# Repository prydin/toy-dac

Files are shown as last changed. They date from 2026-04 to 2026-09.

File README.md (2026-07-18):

# toy-dac

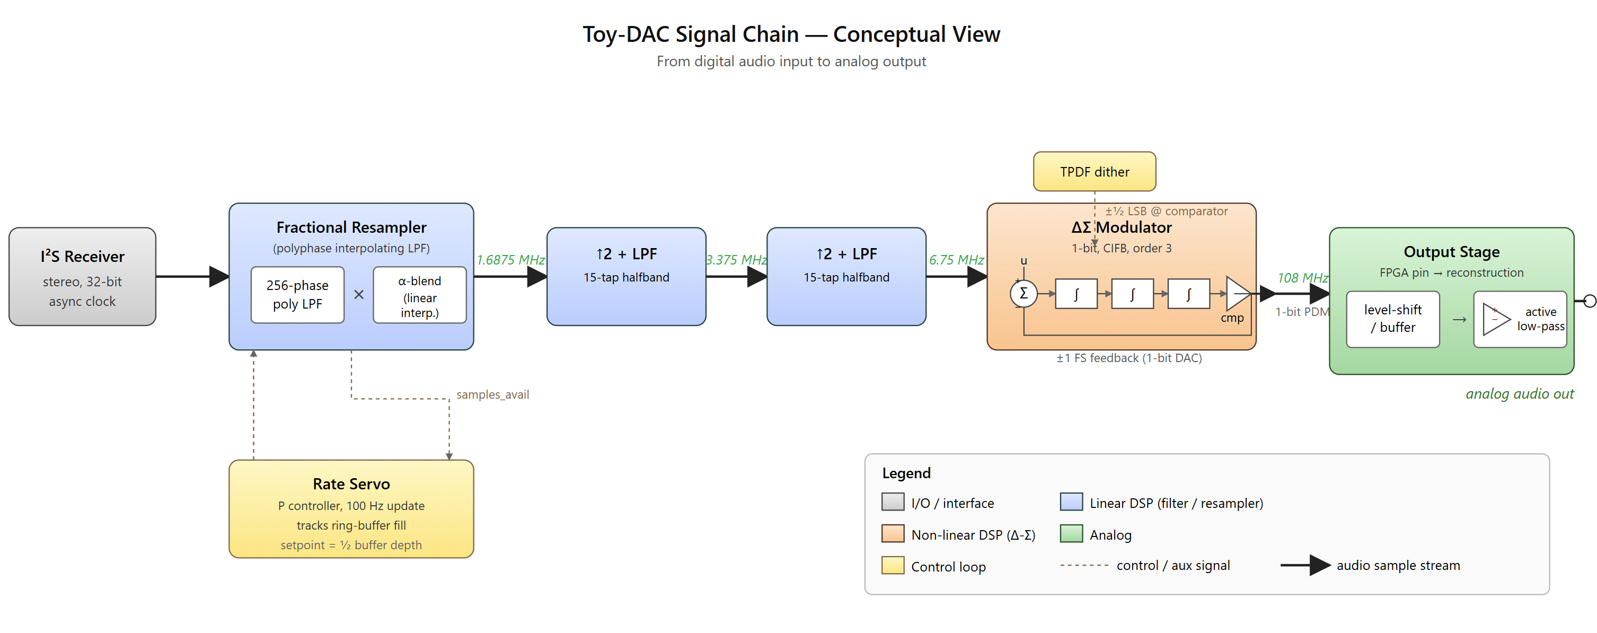
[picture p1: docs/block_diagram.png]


A 1-bit ΔΣ stereo audio DAC implemented on a Xilinx 7-series FPGA
(Digilent Cmod S7), driven from an I²S input.

The signal chain is entirely homemade RTL:

- **I²S receiver** with double-flopped synchronizers and AXI-Stream output
- **Automatic input rate detection** (32 / 44.1 / 48 kHz)
- **Fractional-phase polyphase ASRC** — 256 phases × 64 taps × 18-bit
  coefficients with 16-bit alpha lerp, single time-shared MAC, PI servo
  on the input ring-buffer fill — resampling onto a fixed
  Fs<sub>out</sub> = MCLK / 64 = 1.6875 MHz output grid
- **2nd-order CIFB ΔΣ modulator** (per channel) with TPDF dither,
  driving a single-bit differential output pin pair on each channel
- A small reconstruction filter and analog output stage on the carrier PCB

Internal test sources (silent, DC, 1 kHz DDS sine) and a bypass mode
(raw I²S → modulator) are included for bring-up and characterisation.

Achieved performance with the current build is roughly 70 dB SNR and
−74 dB THD at −7 dBFS, 1 kHz; harmonic distortion is dominated by the
analog stage on the prototype board.

## Status

**Experimental.** This is a personal learning / hobby project. The
design works end-to-end on the target hardware, but it has had limited
testing, no formal verification, and the analog board is a hand-routed
prototype. Module ports, parameter names, and pinouts may change without
notice. Use it for inspiration or as a starting point, not as a drop-in
IP.

## Repository layout

```
fpga/toy-dac/   Vivado project (RTL under src/rtl, constraints under
                toy-dac.srcs/constrs_1, simulation under toy-dac.srcs/sim_1)
kicad/dac/      KiCad schematic + PCB for the analog carrier board
scripts/        Coefficient generation, simulation helpers, sanity checks
docs/           Block diagrams (top-level + ASRC internals)
```

## Building

Open `fpga/toy-dac/toy-dac.xpr` in Vivado 2024.2, run synthesis +
implementation + bitstream generation, and program the Cmod S7. The
target part and pin assignments live in
`fpga/toy-dac/toy-dac.srcs/constrs_1/new/root.xdc`.

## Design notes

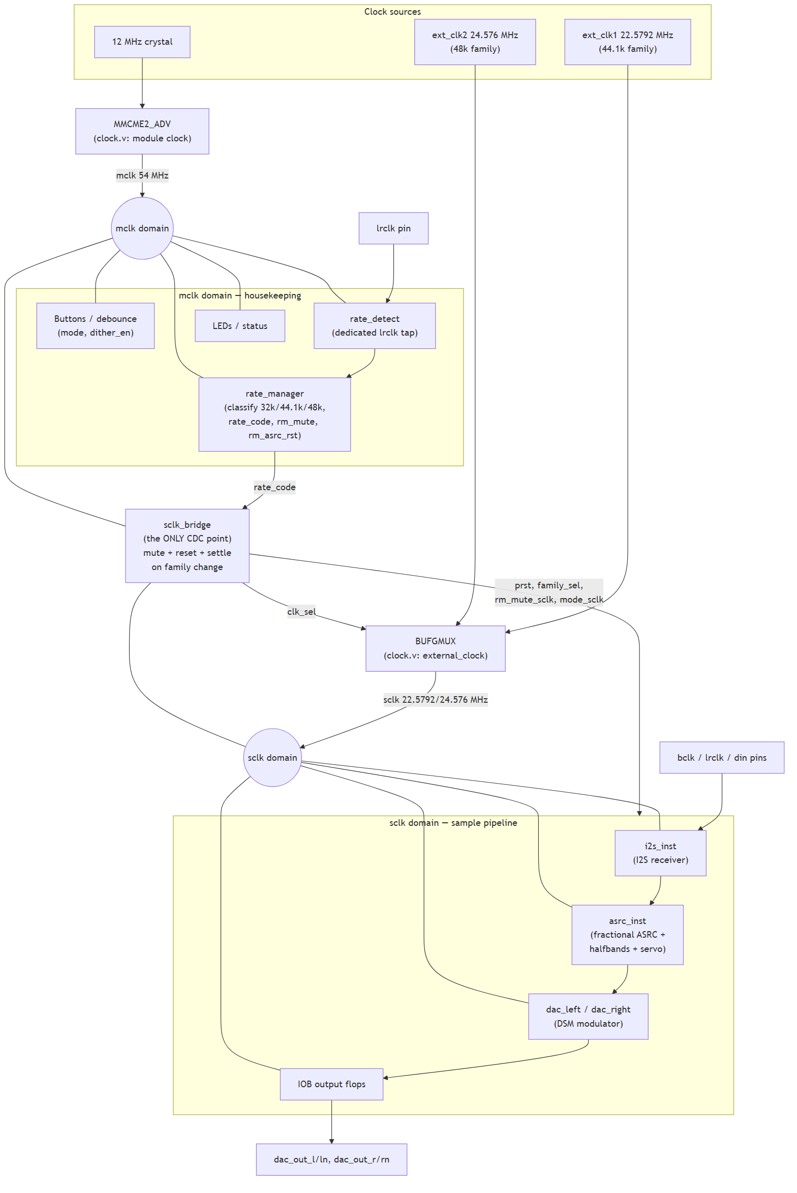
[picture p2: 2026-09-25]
docs/clock_domains.png

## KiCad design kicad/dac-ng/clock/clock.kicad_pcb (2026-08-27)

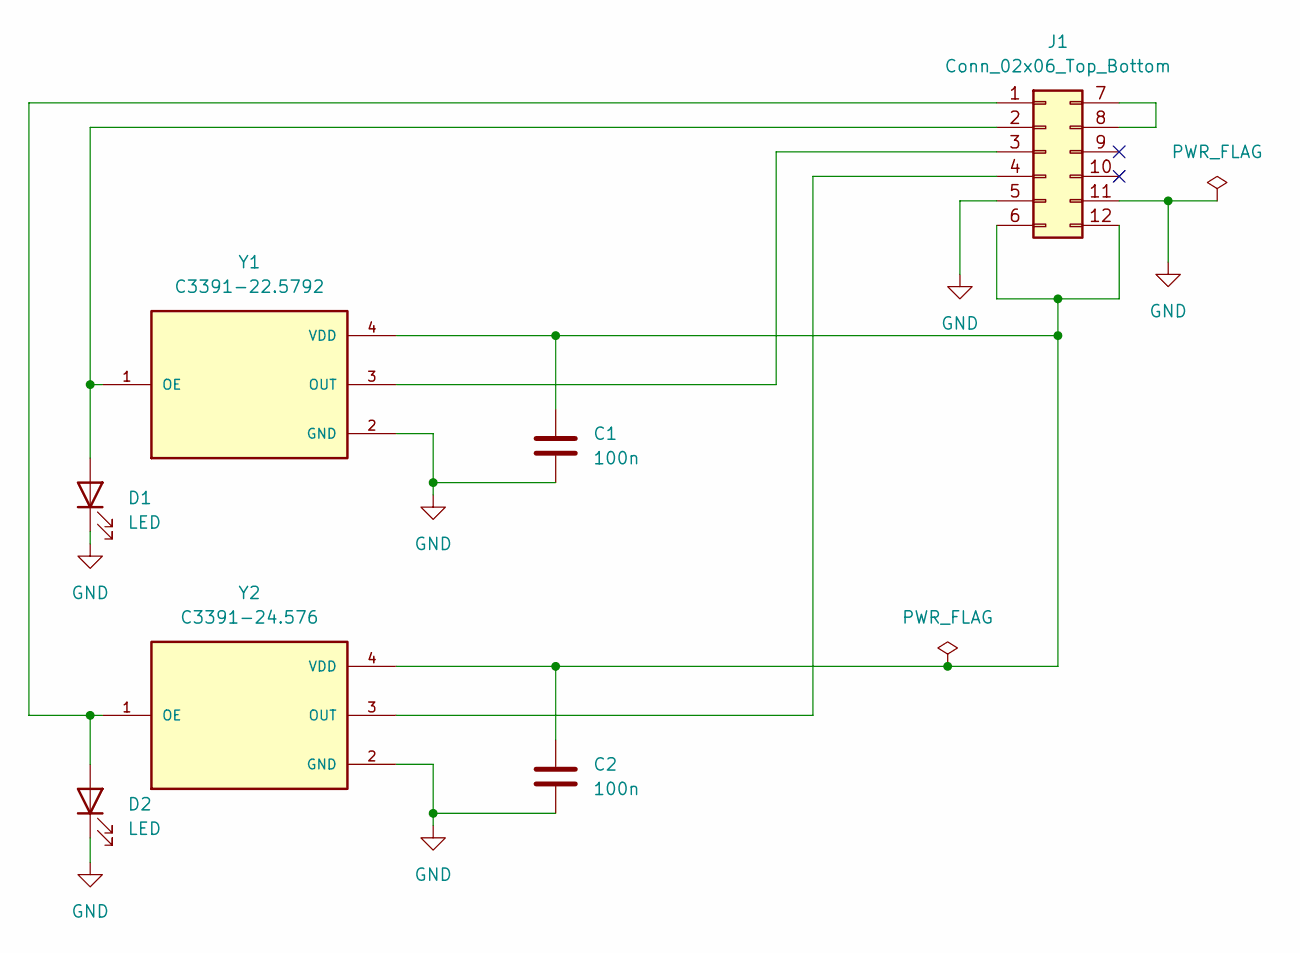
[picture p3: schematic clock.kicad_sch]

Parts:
C1, C2: 100n; C_0603_1608Metric_Pad1.08x0.95mm_HandSolder
D1, D2: LED; LED_0603_1608Metric
J1: Conn_02x06_Top_Bottom; PinHeader_2x06_P2.54mm_Vertical
Y1: C3391-22.5792; Oscillator_SMD_Diodes_FN-4Pin_7.0x5.0mm; PARTREV NA
Y2: C3391-24.576; Oscillator_SMD_Diodes_FN-4Pin_7.0x5.0mm; PARTREV NA

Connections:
GND: C1.2, C2.2, D1.1 (K), D2.1 (K), J1.5, J1.11, Y1.2 (GND), Y2.2 (GND)
unnamed: D1.2 (A), J1.2, Y1.1 (OE)
unnamed: D2.2 (A), J1.1, Y2.1 (OE)
unnamed: J1.3, Y1.3 (OUT)
unnamed: J1.4, Y2.3 (OUT)
unnamed: J1.7, J1.8
unnamed: C1.1, C2.1, J1.6, J1.12, Y1.4 (VDD), Y2.4 (VDD)

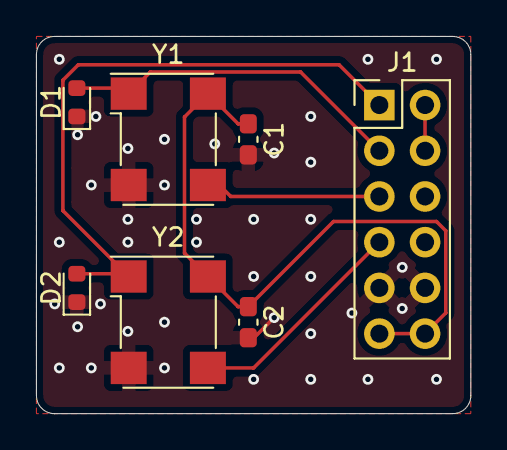
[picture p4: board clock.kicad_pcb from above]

Board: 2 copper layers, 24.1 x 21.0 mm, 7 parts (0 on the bottom side), 7 nets.

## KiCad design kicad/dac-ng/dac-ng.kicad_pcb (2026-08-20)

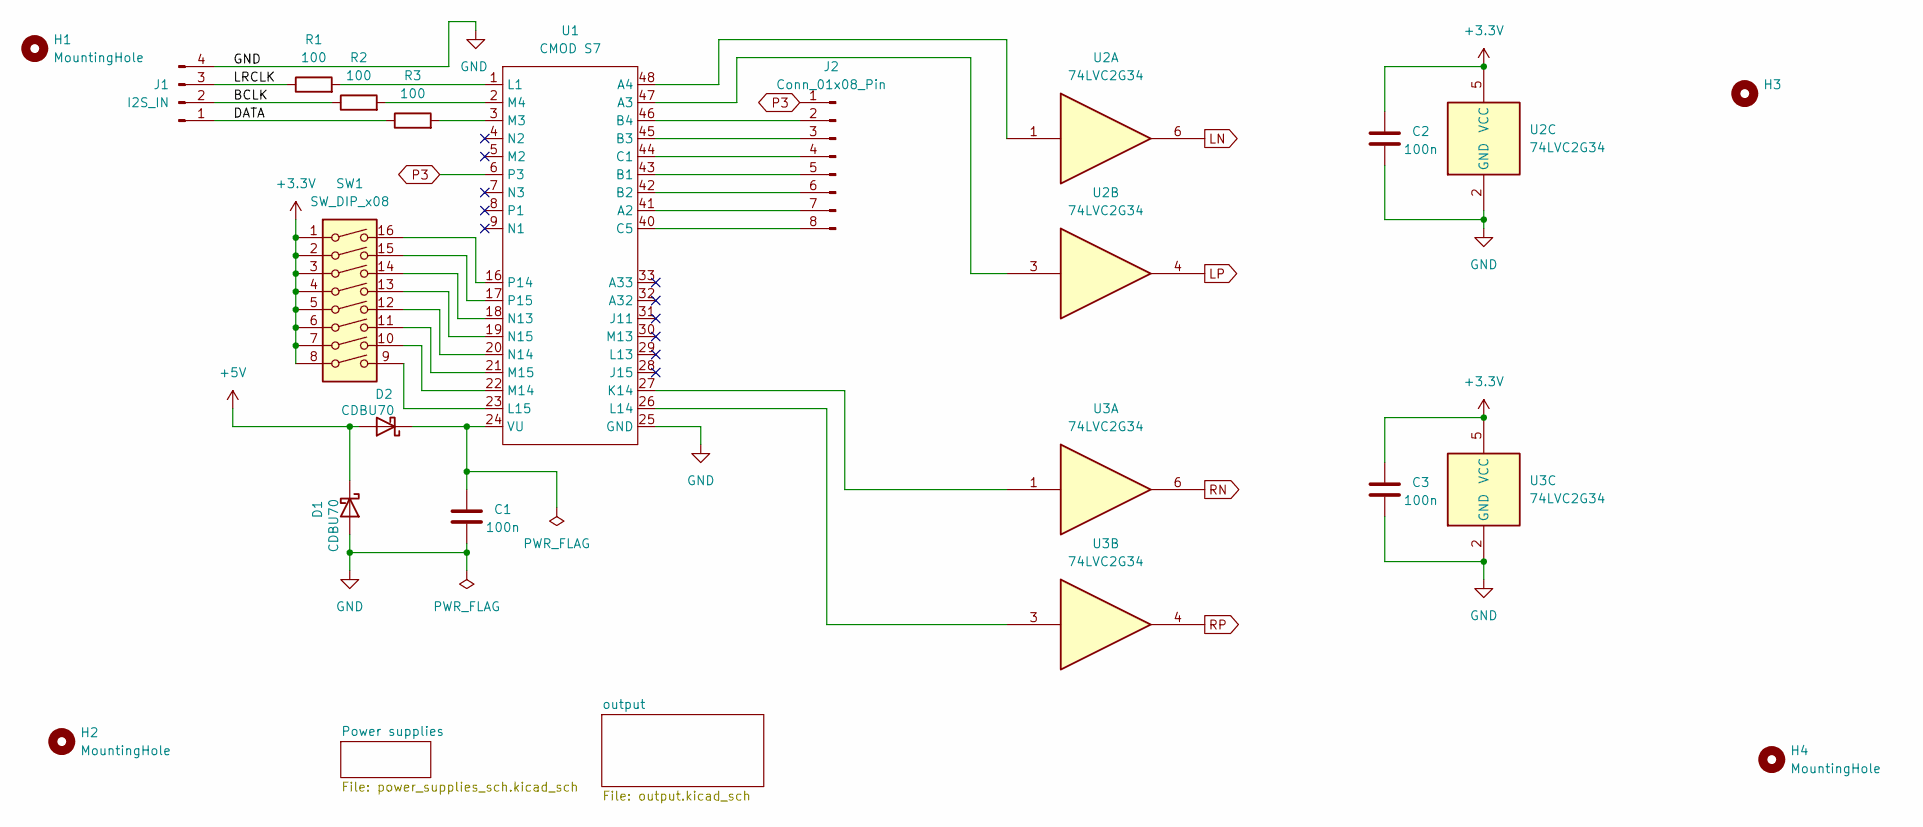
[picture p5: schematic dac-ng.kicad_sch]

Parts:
C1, C2, C3: 100n; C_0603_1608Metric_Pad1.08x0.95mm_HandSolder
D1, D2: CDBU70; D_0603_1608Metric
H1, H2, H3, H4: MountingHole; MountingHole_3.2mm_M3
J1: I2S_IN; JST_PH_B4B-PH-K_1x04_P2.00mm_Vertical
J2: Conn_01x08_Pin; PinHeader_1x08_P2.54mm_Vertical
R1, R2, R3: 100; R_0603_1608Metric_Pad0.98x0.95mm_HandSolder
SW1: SW_DIP_x08; SW_DIP_SPSTx08_Slide_6.7x21.88mm_W7.62mm_P2.54mm_LowProfile
U1: CMOD S7
U2, U3: 74LVC2G34; SOT-363_SC-70-6

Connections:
+3.3V: C2.2, C3.2, SW1.1, SW1.2, SW1.3, SW1.4, SW1.5, SW1.6, SW1.7, SW1.8, U2.5 (VCC), U3.5 (VCC); also elsewhere on the board
+5V: D1.1 (K), D2.2 (A); also elsewhere on the board
/BCLK: J1.2, R2.1
/DATA: J1.1, R3.1
/LRCLK: J1.3, R1.1
GND: C1.1, C2.1, C3.1, D1.2 (A), J1.4, U1.25 (GND), U2.2 (GND), U3.2 (GND); also elsewhere on the board
LN: U2.6; also elsewhere on the board
LP: U2.4; also elsewhere on the board
unnamed: C1.2, D2.1 (K), U1.24 (VU)
unnamed: J2.2, U1.46 (B4)
unnamed: J2.3, U1.45 (B3)
unnamed: J2.4, U1.44 (C1)
unnamed: J2.5, U1.43 (B1)
unnamed: J2.6, U1.42 (B2)
unnamed: J2.7, U1.41 (A2)
unnamed: J2.8, U1.40 (C5)
unnamed: U1.47 (A3), U2.3
unnamed: U1.48 (A4), U2.1
unnamed: U1.27 (K14), U3.1
unnamed: R1.2, U1.1 (L1)
unnamed: U1.26 (L14), U3.3
unnamed: SW1.9, U1.23 (L15)
unnamed: R3.2, U1.3 (M3)
unnamed: R2.2, U1.2 (M4)
unnamed: SW1.10, U1.22 (M14)
unnamed: SW1.11, U1.21 (M15)
unnamed: SW1.14, U1.18 (N13)
unnamed: SW1.12, U1.20 (N14)
unnamed: SW1.13, U1.19 (N15)
unnamed: SW1.16, U1.16 (P14)
unnamed: SW1.15, U1.17 (P15)
P3: J2.1, U1.6 (P3)
RN: U3.6; also elsewhere on the board
RP: U3.4; also elsewhere on the board

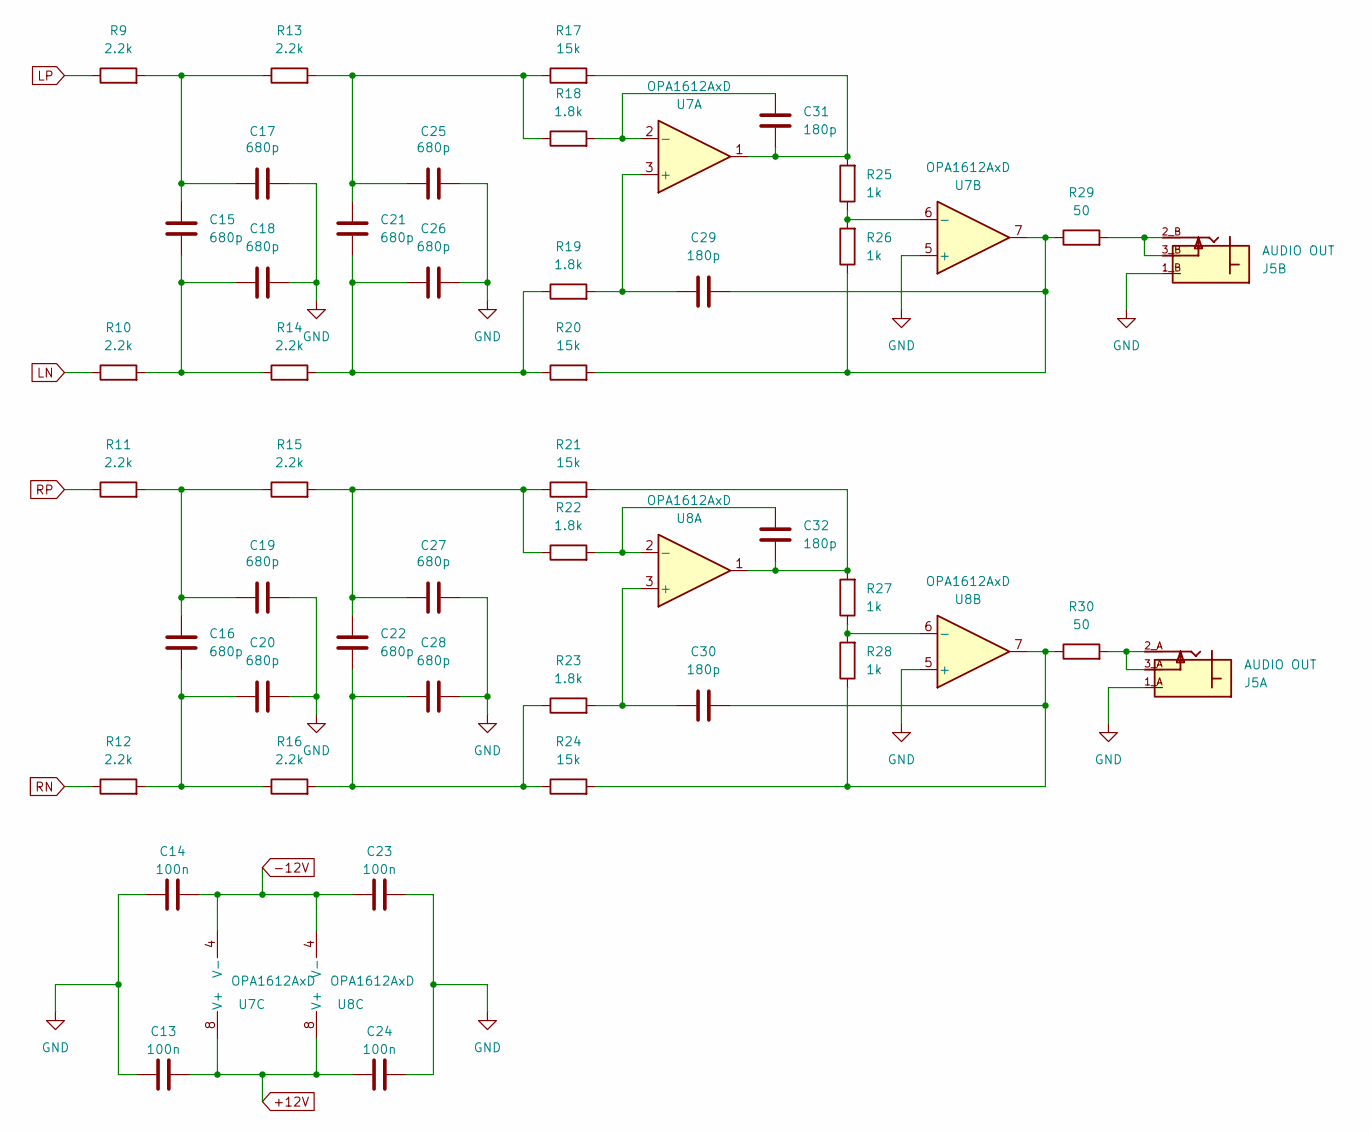
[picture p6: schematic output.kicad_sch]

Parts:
C13, C14, C23, C24: 100n; C_0603_1608Metric_Pad1.08x0.95mm_HandSolder
C15, C16, C17, C18, C19, C20, C21, C22, C25, C26, C27, C28: 680p; C_0603_1608Metric_Pad1.08x0.95mm_HandSolder
C29, C30, C31, C32: 180p; C_0603_1608Metric_Pad1.08x0.95mm_HandSolder
J5: AUDIO OUT; SWITCHCRAFT_PJRAN2X1U01AUX
R9, R10, R11, R12, R13, R14, R15, R16: 2.2k; R_0603_1608Metric_Pad0.98x0.95mm_HandSolder
R17, R20, R21, R24: 15k; R_0603_1608Metric_Pad0.98x0.95mm_HandSolder
R18, R19, R22, R23: 1.8k; R_0603_1608Metric_Pad0.98x0.95mm_HandSolder
R25, R26, R27, R28: 1k; R_0603_1608Metric_Pad0.98x0.95mm_HandSolder
R29, R30: 50; R_0603_1608Metric_Pad0.98x0.95mm_HandSolder
U7, U8: OPA1612AxD; SOIC-8_5.3x5.3mm_P1.27mm

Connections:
+12V: C13.2, C24.2, U7.8 (V+), U8.8 (V+); also elsewhere on the board
-12V: C14.2, C23.2, U7.4 (V-), U8.4 (V-); also elsewhere on the board
GND: C13.1, C14.1, C17.2, C18.2, C19.2, C20.2, C23.1, C24.1, C25.2, C26.2, C27.2, C28.2, J5.1_A, J5.1_B, U7.5 (+), U8.5 (+); also elsewhere on the board
LN: R10.1; also elsewhere on the board
LP: R9.1; also elsewhere on the board
unnamed: C15.1, C17.1, R9.2, R13.1
unnamed: C15.2, C18.1, R10.2, R14.1
unnamed: C16.1, C19.1, R11.2, R15.1
unnamed: C16.2, C20.1, R12.2, R16.1
unnamed: C21.1, C25.1, R13.2, R17.1, R18.1
unnamed: C21.2, C26.1, R14.2, R19.1, R20.1
unnamed: C22.1, C27.1, R15.2, R21.1, R22.1
unnamed: C22.2, C28.1, R16.2, R23.1, R24.1
unnamed: C29.2, R20.2, R26.1, R29.1, U7.7
unnamed: C30.2, R24.2, R28.1, R30.1, U8.7
unnamed: C31.2, R17.2, R25.2, U7.1
unnamed: C32.2, R21.2, R27.2, U8.1
unnamed: J5.2_A, J5.3_A, R30.2
unnamed: J5.2_B, J5.3_B, R29.2
unnamed: C29.1, R19.2, U7.3 (+)
unnamed: C31.1, R18.2, U7.2 (-)
unnamed: R25.1, R26.2, U7.6 (-)
unnamed: C30.1, R23.2, U8.3 (+)
unnamed: C32.1, R22.2, U8.2 (-)
unnamed: R27.1, R28.2, U8.6 (-)
RN: R12.1; also elsewhere on the board
RP: R11.1; also elsewhere on the board

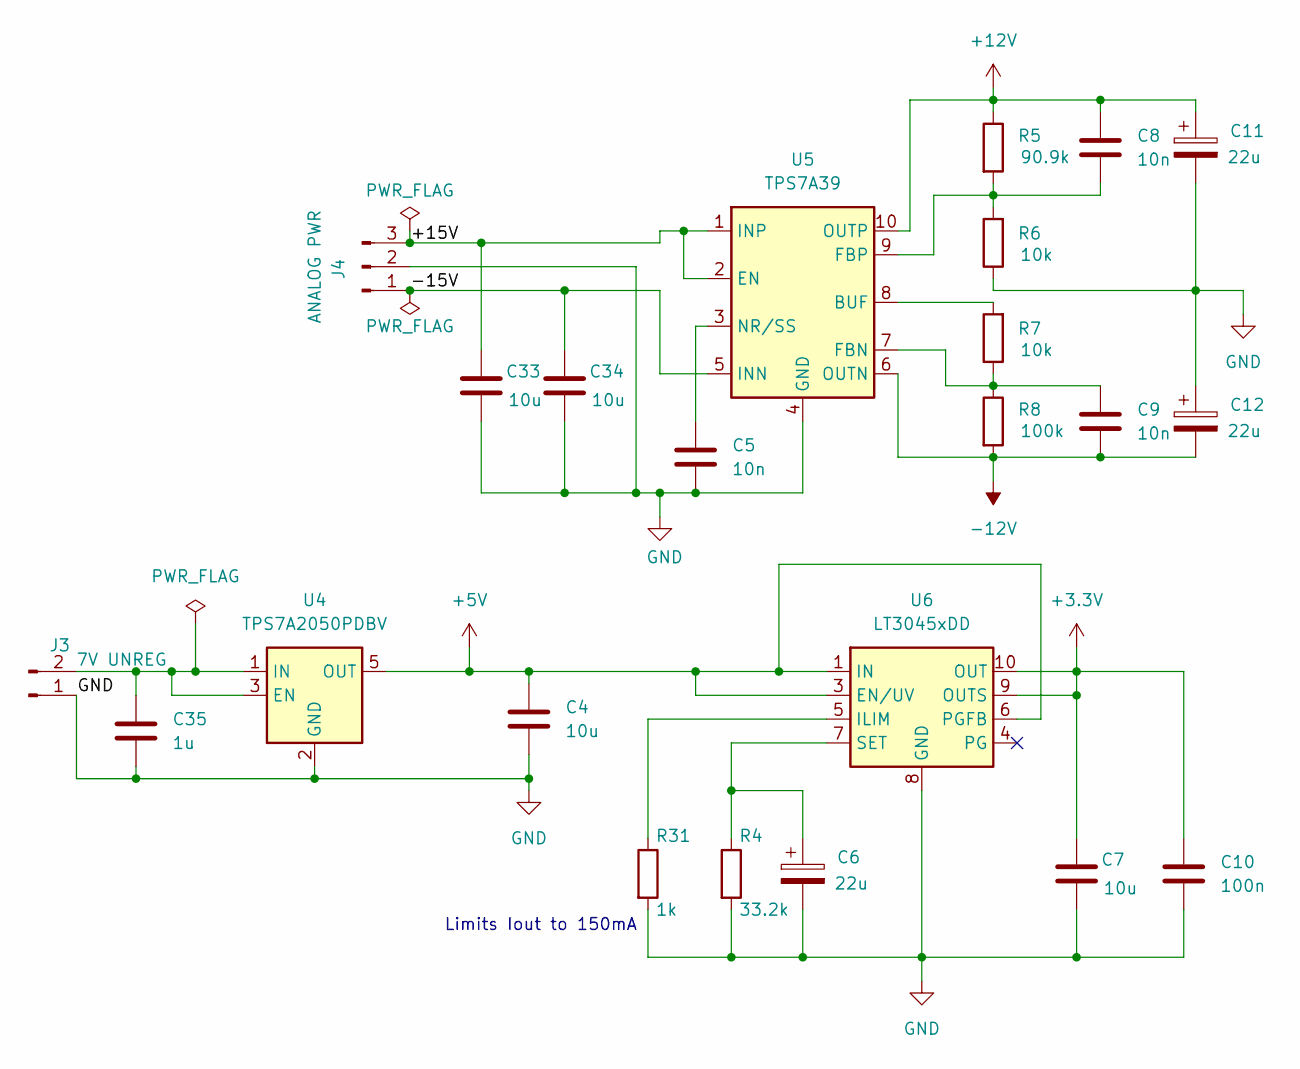
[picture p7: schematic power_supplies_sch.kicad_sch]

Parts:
C4, C7, C33, C34: 10u; C_0805_2012Metric
C5, C8, C9: 10n; C_0603_1608Metric_Pad1.08x0.95mm_HandSolder
C6, C11, C12: 22u; CP_EIA-3216-10_Kemet-I_HandSolder
C10: 100n; C_0603_1608Metric_Pad1.08x0.95mm_HandSolder
C35: 1u; C_0603_1608Metric
J3: 7V UNREG; JST_PH_B2B-PH-K_1x02_P2.00mm_Vertical
J4: ANALOG PWR; JST_PH_B3B-PH-K_1x03_P2.00mm_Vertical
R4: 33.2k; R_0603_1608Metric_Pad0.98x0.95mm_HandSolder
R5: 90.9k; R_0603_1608Metric_Pad0.98x0.95mm_HandSolder
R6, R7: 10k; R_0603_1608Metric_Pad0.98x0.95mm_HandSolder
R8: 100k; R_0603_1608Metric_Pad0.98x0.95mm_HandSolder
R31: 1k; R_0603_1608Metric_Pad0.98x0.95mm_HandSolder
U4: TPS7A2050PDBV; SOT-23-5
U5: TPS7A39; Texas_S-PVSON-N10_ThermalVias
U6: LT3045xDD; DFN-10-1EP_3x3mm_P0.5mm_EP1.65x2.38mm

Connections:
+3.3V: C7.1, C10.1, U6.9 (OUTS), U6.10 (OUT); also elsewhere on the board
+5V: C4.1, U4.5 (OUT), U6.1 (IN), U6.2 (IN), U6.3 (EN/UV), U6.6 (PGFB); also elsewhere on the board
+12V: C8.1, C11.1, R5.1, U5.10 (OUTP); also elsewhere on the board
-12V: C9.2, C12.2, R8.2, U5.6 (OUTN); also elsewhere on the board
/Power supplies/+15V: C33.1, J4.3, U5.1 (INP), U5.2 (EN)
/Power supplies/-15V: C34.1, J4.1, U5.5 (INN)
GND: C4.2, C5.2, C6.2, C7.2, C10.2, C11.2, C12.1, C33.2, C34.2, C35.2, J3.1, J4.2, R4.2, R6.1, R31.2, U4.2 (GND), U5.4 (GND), U5.11 (GND), U6.8 (GND), U6.11 (GND); also elsewhere on the board
unnamed: C35.1, J3.2, U4.1 (IN), U4.3 (EN)
unnamed: R7.2, U5.8 (BUF)
unnamed: C9.1, R7.1, R8.1, U5.7 (FBN)
unnamed: C8.2, R5.2, R6.2, U5.9 (FBP)
unnamed: C5.1, U5.3 (NR/SS)
unnamed: R31.1, U6.5 (ILIM)
unnamed: C6.1, R4.1, U6.7 (SET)

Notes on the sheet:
Limits Iout to 150mA

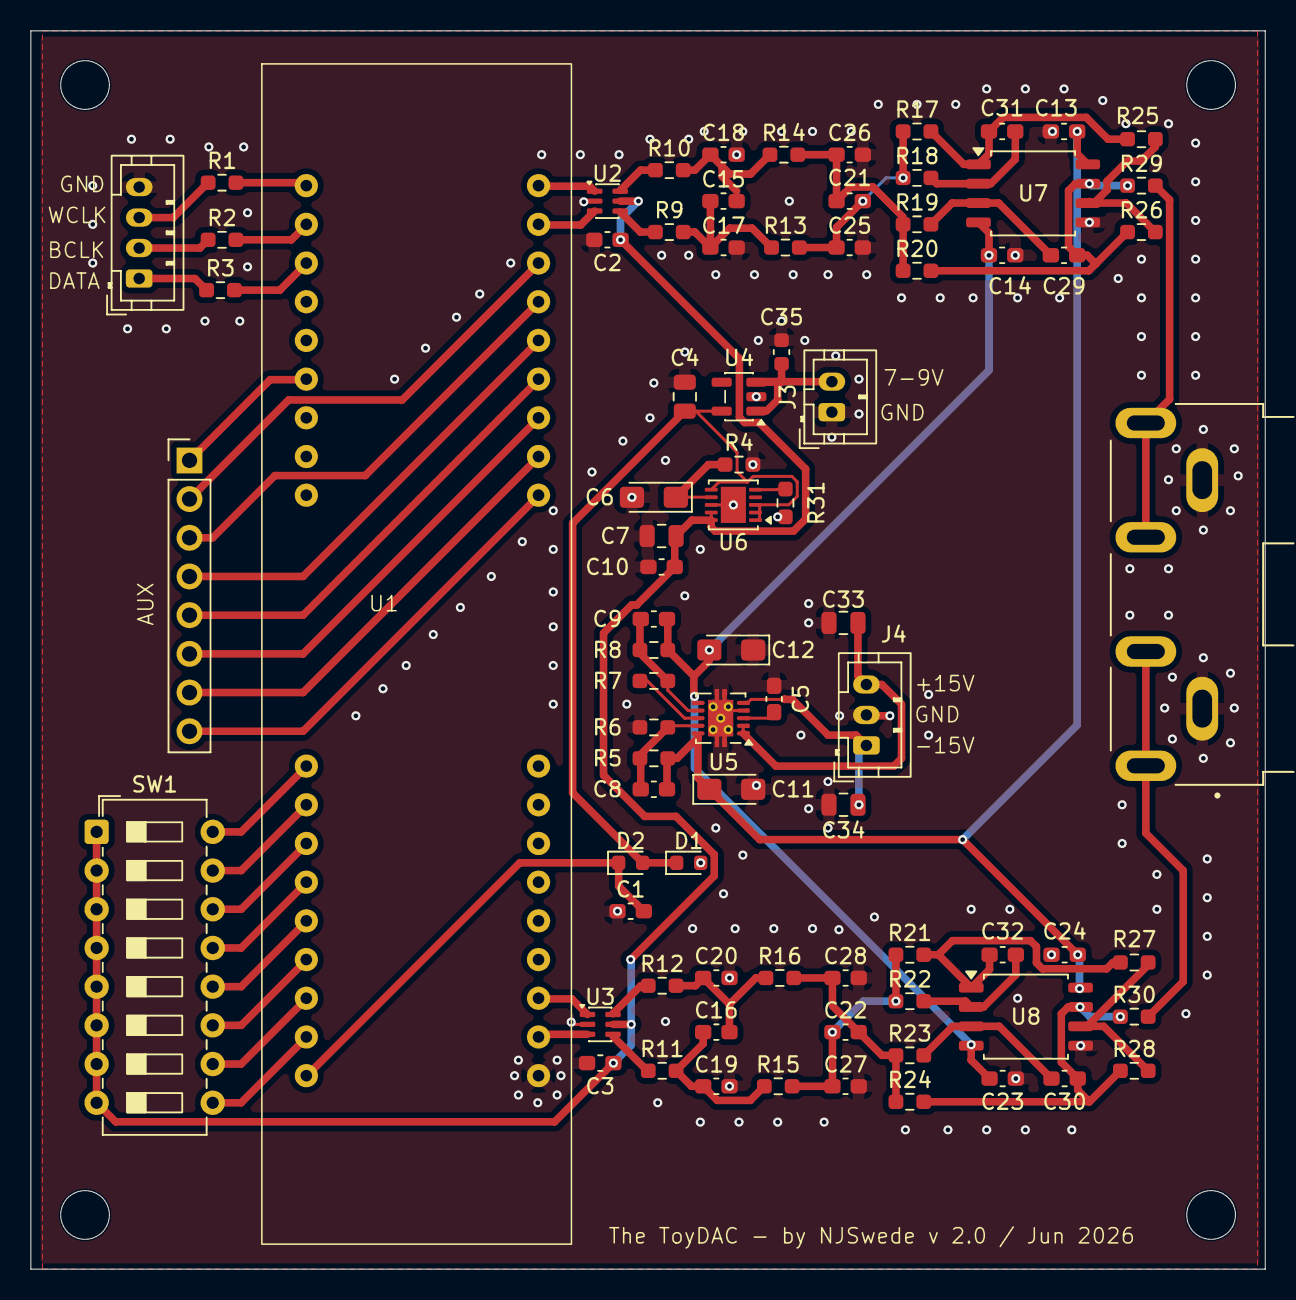
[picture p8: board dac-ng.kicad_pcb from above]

Board: 4 copper layers, 81.0 x 81.3 mm, 86 parts (0 on the bottom side), 65 nets.

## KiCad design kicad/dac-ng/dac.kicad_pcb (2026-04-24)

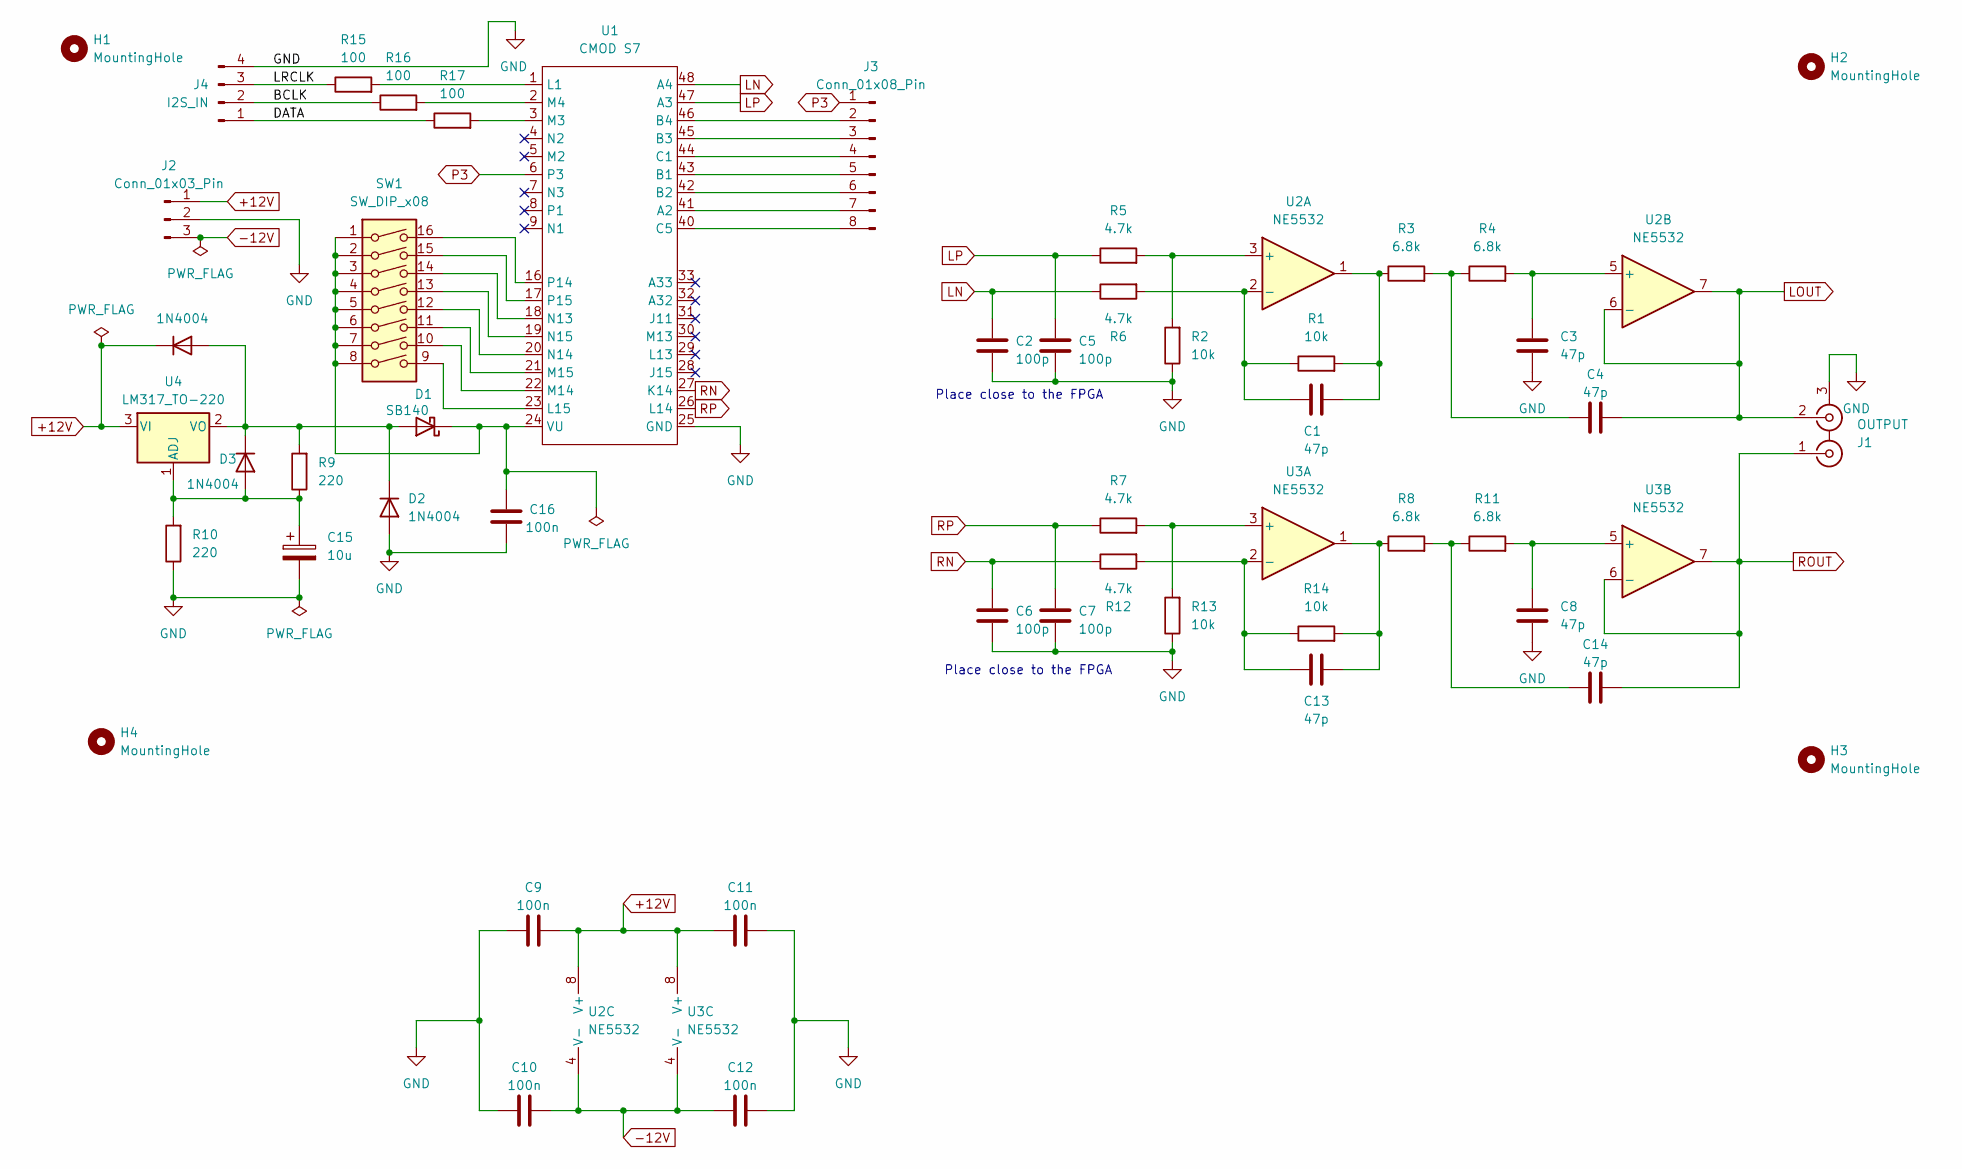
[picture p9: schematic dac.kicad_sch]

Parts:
C1, C3, C4, C8, C13, C14: 47p; C_Rect_L7.2mm_W3.0mm_P5.00mm_FKS2_FKP2_MKS2_MKP2_HandSolder
C2, C5, C6, C7: 100p; C_Rect_L7.2mm_W3.0mm_P5.00mm_FKS2_FKP2_MKS2_MKP2_HandSolder
C9, C10, C11, C12, C16: 100n; C_Rect_L7.2mm_W3.0mm_P5.00mm_FKS2_FKP2_MKS2_MKP2_HandSolder
C15: 10u; CP_Radial_D8.0mm_P5.00mm
D1: SB140; D_DO-41_SOD81_P10.16mm_Horizontal
D2, D3, D4: 1N4004; D_DO-41_SOD81_P10.16mm_Horizontal
H1, H2, H3, H4: MountingHole; MountingHole_3.2mm_M3
J1: OUTPUT; Basic RCA
J2: Conn_01x03_Pin; JST_PH_B3B-PH-K_1x03_P2.00mm_Vertical
J3: Conn_01x08_Pin; PinHeader_1x08_P2.54mm_Vertical
J4: I2S_IN; JST_PH_B4B-PH-K_1x04_P2.00mm_Vertical
R1, R2, R13, R14: 10k; R_Axial_DIN0204_L3.6mm_D1.6mm_P7.62mm_Horizontal_HandSolder
R3, R4, R8, R11: 6.8k; R_Axial_DIN0204_L3.6mm_D1.6mm_P7.62mm_Horizontal_HandSolder
R5, R6, R7, R12: 4.7k; R_Axial_DIN0204_L3.6mm_D1.6mm_P7.62mm_Horizontal_HandSolder
R9, R10: 220; R_Axial_DIN0204_L3.6mm_D1.6mm_P7.62mm_Horizontal_HandSolder
R15, R16, R17: 100; R_Axial_DIN0204_L3.6mm_D1.6mm_P7.62mm_Horizontal_HandSolder
SW1: SW_DIP_x08; SW_DIP_SPSTx08_Slide_6.7x21.88mm_W7.62mm_P2.54mm_LowProfile
U1: CMOD S7
U2, U3: NE5532; DIP-8_W7.62mm
U4: LM317_TO-220; TO-220-3_Vertical

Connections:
+12V: C9.2, C11.2, D4.1 (K), J2.1, U2.8 (V+), U3.8 (V+), U4.3 (VI)
-12V: C10.2, C12.2, J2.3, U2.4 (V-), U3.4 (V-)
/BCLK: J4.2, R16.1
/DATA: J4.1, R17.1
/LRCLK: J4.3, R15.1
GND: C2.2, C3.2, C5.2, C6.2, C7.2, C8.2, C9.1, C10.1, C11.1, C12.1, C15.2, C16.1, D2.2 (A), J1.3 (EXT), J2.2, J4.4, R2.1, R10.1, R13.1, U1.25 (GND)
LN: C2.1, R6.1, U1.48 (A4)
LOUT: C4.2, J1.2 (IN2), U2.6 (-), U2.7
LP: C5.1, R5.1, U1.47 (A3)
unnamed: C1.1, R1.2, R3.1, U2.1
unnamed: C4.1, R3.2, R4.1
unnamed: C13.1, R8.1, R14.2, U3.1
unnamed: C14.1, R8.2, R11.1
unnamed: D1.2 (A), D2.1 (K), D3.1 (K), D4.2 (A), R9.2, U4.2 (VO)
unnamed: C16.2, D1.1 (K), SW1.1, SW1.2, SW1.3, SW1.4, SW1.5, SW1.6, SW1.7, SW1.8, U1.24 (VU)
unnamed: C15.1, D3.2 (A), R9.1, R10.2, U4.1 (ADJ)
unnamed: J3.2, U1.46 (B4)
unnamed: J3.3, U1.45 (B3)
unnamed: J3.4, U1.44 (C1)
unnamed: J3.5, U1.43 (B1)
unnamed: J3.6, U1.42 (B2)
unnamed: J3.7, U1.41 (A2)
unnamed: J3.8, U1.40 (C5)
unnamed: R15.2, U1.1 (L1)
unnamed: SW1.9, U1.23 (L15)
unnamed: R17.2, U1.3 (M3)
unnamed: R16.2, U1.2 (M4)
unnamed: SW1.10, U1.22 (M14)
unnamed: SW1.11, U1.21 (M15)
unnamed: SW1.14, U1.18 (N13)
unnamed: SW1.12, U1.20 (N14)
unnamed: SW1.13, U1.19 (N15)
unnamed: SW1.16, U1.16 (P14)
unnamed: SW1.15, U1.17 (P15)
unnamed: R2.2, R5.2, U2.3 (+)
unnamed: C1.2, R1.1, R6.2, U2.2 (-)
unnamed: C3.1, R4.2, U2.5 (+)
unnamed: R7.2, R13.2, U3.3 (+)
unnamed: C13.2, R12.2, R14.1, U3.2 (-)
unnamed: C8.1, R11.2, U3.5 (+)
P3: J3.1, U1.6 (P3)
RN: C6.1, R12.1, U1.27 (K14)
ROUT: C14.2, J1.1 (IN1), U3.6 (-), U3.7
RP: C7.1, R7.1, U1.26 (L14)

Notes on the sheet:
Place close to the FPGA

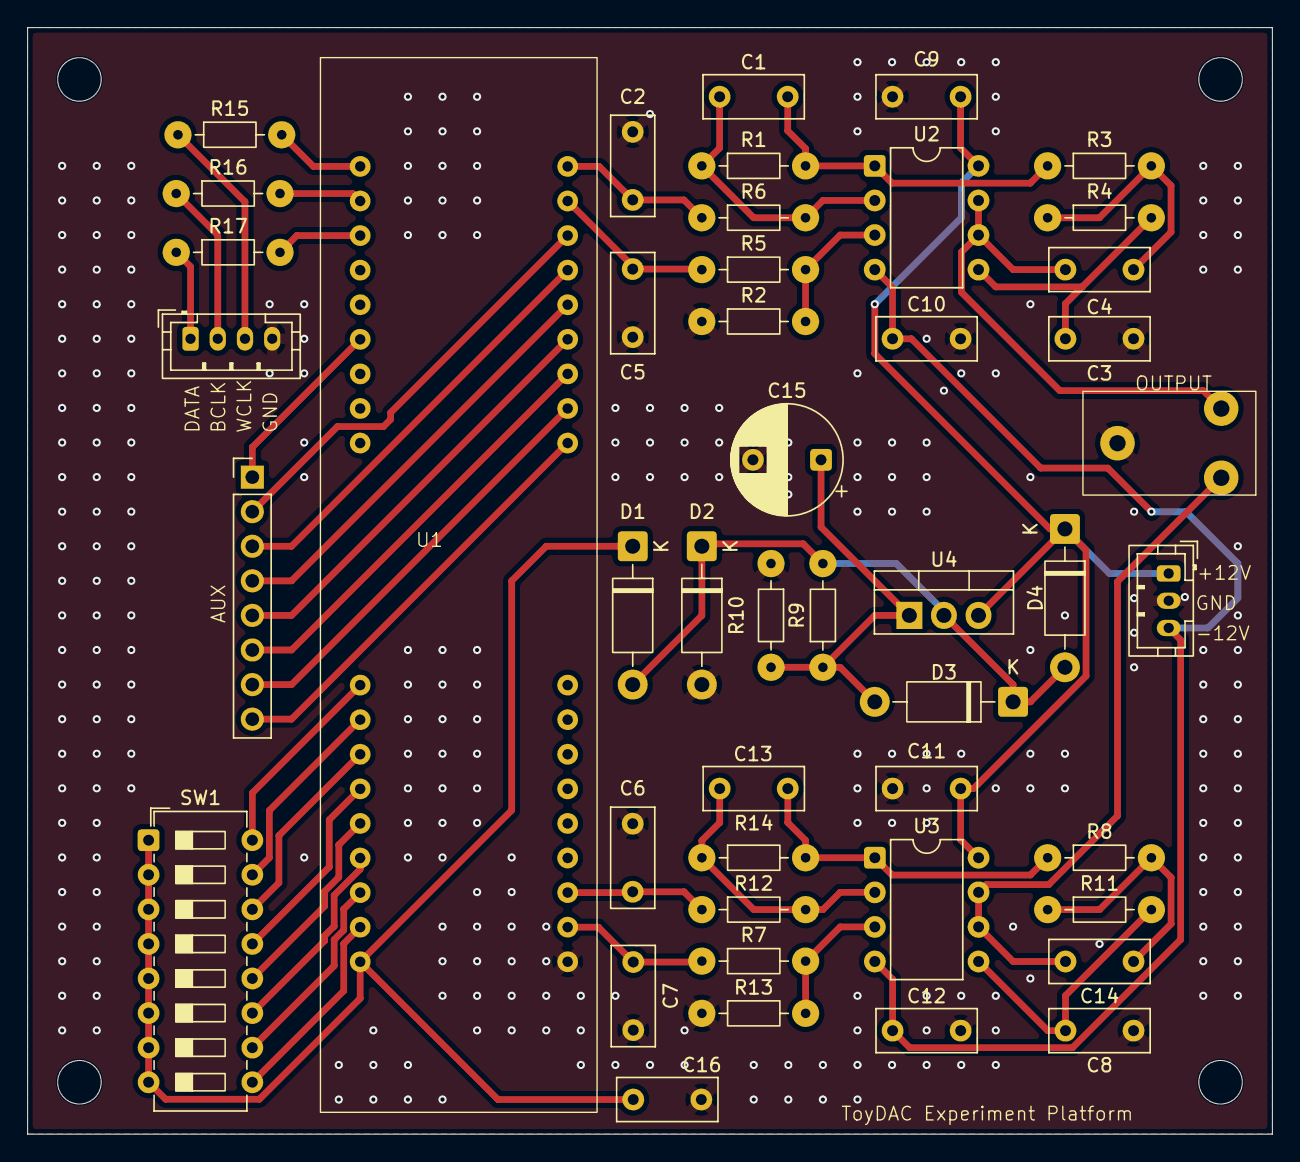
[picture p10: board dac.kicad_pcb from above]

Board: 4 copper layers, 91.4 x 81.3 mm, 50 parts (0 on the bottom side), 44 nets.

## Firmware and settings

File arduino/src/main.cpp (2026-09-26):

#include <Arduino.h>
#include <LiquidCrystal_I2C.h>
#include <OneButton.h>
#include "AcceleratedRotaryEncoder.h"
constexpr uint8_t kLcdAddress = 0x27;
constexpr uint8_t kLcdColumns = 20;
constexpr uint8_t kLcdRows = 4;
constexpr uint8_t kDACdAddress = 0x50;
constexpr time_t kBounceGuardDuration = 200; // in milliseconds

// DAC Control bits and registers
constexpr uint8_t kDACRateRegister = 0;
constexpr uint8_t kDACFifoRegister = 1;
constexpr uint8_t kDACStatusRegister = 2;
constexpr uint8_t kDACControlRegister = 3;
constexpr uint8_t kDACASRCErrorRegister0 = 4;
constexpr uint8_t kDACASRCErrorRegister1 = 5;
constexpr uint8_t kDACAdjustmentRegister0 = 6;
constexpr uint8_t kDACAdjustmentRegister1 = 7;
constexpr uint8_t kDACAdjustmentRegister2 = 8;
constexpr uint8_t kDACAdjustmentRegister3 = 9;
constexpr uint8_t kDACVolumetRegister = 12;


// Control bits for the DAC
constexpr uint8_t kDACControlDither = 0; 
constexpr uint8_t kDACControlTestTone = 1;
constexpr uint8_t kDACControlInhibitInterpolation = 2;
constexpr uint8_t kDACControlOutputMute = 3;
constexpr uint8_t kDACControlInputMute = 4;

AcceleratedRotaryEncoder volumeKnob(1, 4); // Pins 1 and 4 for the rotary encoder

typedef struct DACStatus
{
    float fs;
    uint8_t fifoFullness;
    bool rateLocked;
    bool ditherEnabled;
    bool testToneEnabled;
    bool inhibitInterpolation;
    bool inputMute;
    bool outputMute;
    float volume;
    int32_t asrcAdjustment;
    int16_t asrcError;
} DACStatus;

LiquidCrystal_I2C lcd(kLcdAddress, kLcdColumns, kLcdRows);

OneButton ditherButton(3, true); // Pin 3, active low
bool ditherEnabled = true;
bool forceDisplayUpdate = true;

// Increments locally with no I2C involved, isolates Arduino-side bugs from bus/DAC issues.
uint16_t debugCounter = 0;

void printDACStatus(const DACStatus &status)
{
    lcd.setCursor(0, 0);
    lcd.print("Dit: " + String(status.ditherEnabled ? "On " : "Off"));
    lcd.setCursor(10, 0);
    lcd.print("FIR: " + String(status.inhibitInterpolation ? "Off" : "On "));
//    lcd.setCursor(0, 1);
//    lcd.print("DAC Status: OK");
    lcd.setCursor(0, 1);
    lcd.print((status.rateLocked ? String(status.fs, 1) : "--.-") + "kHz");
    lcd.setCursor(10, 1);
    lcd.print("FIFO: " + String(status.fifoFullness) + "% ");
    lcd.setCursor(7, 3);
    lcd.print(String(status.volume, 2) + "dB  ");
    lcd.setCursor(0, 2);
    char bar[21];
    int8_t barLength = (80 + status.volume) / 4;
    if (barLength < 0) barLength = 0;
    if (barLength > 20) barLength = 20;
    for (int i = 0; i < 20; i++) {
        bar[i] = i < barLength ? (char) 255 : ' ';
    }
    bar[20] = '\0';
    lcd.print(bar);
}

bool readDACRegister(uint8_t reg, uint8_t &value)
{
    Wire.beginTransmission(kDACdAddress);
    Wire.write(reg);
    if (Wire.endTransmission(false) != 0)
    {
        Serial.printf("Failed to select DAC reg %02X\n", reg);
        return false;
    }
    if (Wire.requestFrom(kDACdAddress, (uint8_t)1) != 1)
    {
        return false;
    }
    if (Wire.available() == 1)
    {
        value = Wire.read();
        Serial.printf("Read byte from reg %02X: %02X\n", reg, value);
        return true;
    }
    Serial.printf("Failed to read byte from reg %02X\n", reg);
    return false;
}

bool writeDACRegister(uint8_t reg, uint8_t value)
{
    Wire.beginTransmission(kDACdAddress);
    Wire.write(reg);
    Wire.write(value);
    if (Wire.endTransmission() != 0)
    {
        Serial.printf("Failed to write byte to reg %02X\n", reg);
        return false;
    }
    Serial.printf("Wrote byte to reg %02X: %02X\n", reg, value);
    return true;
}

void readDACStatus(DACStatus &status)
{
    uint8_t fsByte, fifoByte, controlByte, adjustment0, adjustment1, adjustment2, adjustment3, asrcError0, asrcError1, volumeByte;
    if(readDACRegister(kDACVolumetRegister, volumeByte)) {
        status.volume = -((float)volumeByte)/2;
    }
    if (readDACRegister(0, fsByte))
    {
        status.fs = fsByte & 0x80 ? 48.0 * float(fsByte & 0x7) : 44.1 * float(fsByte & 0x7);
    }
    if(readDACRegister(1, fifoByte)) {
        status.fifoFullness = fifoByte / 255.0 * 100;
    }
    
    status.rateLocked = fsByte != 0;
    
    if(readDACRegister(kDACControlRegister, controlByte)) { 
        status.ditherEnabled = (controlByte & (1 << kDACControlDither)) != 0;
    }
    if(readDACRegister(kDACControlRegister, controlByte)) {
        status.testToneEnabled = (controlByte & (1 << kDACControlTestTone)) != 0;
        status.inhibitInterpolation = (controlByte & (1 << kDACControlInhibitInterpolation)) != 0;
        status.inputMute = (controlByte & (1 << kDACControlInputMute)) != 0;
        status.outputMute = (controlByte & (1 << kDACControlOutputMute)) != 0;
    }
    if(readDACRegister(kDACAdjustmentRegister0, adjustment0) &&
       readDACRegister(kDACAdjustmentRegister1, adjustment1) &&
       readDACRegister(kDACAdjustmentRegister2, adjustment2) &&
       readDACRegister(kDACAdjustmentRegister3, adjustment3))
    {
        status.asrcAdjustment = (uint32_t(adjustment0) ) |
                                (uint32_t(adjustment1) << 8) |
                                (uint32_t(adjustment2) << 16) |
                                (uint32_t(adjustment3) << 24);
    }
    if(readDACRegister(kDACASRCErrorRegister0, asrcError0) &&
       readDACRegister(kDACASRCErrorRegister1, asrcError1))
    {
        status.asrcError = (uint16_t(asrcError0) ) |
                           (uint16_t(asrcError1) << 8);
    }
}

void updateDACControl(uint8_t controlValue, uint8_t updateMask)
{
    uint8_t currentValue;
    if (readDACRegister(kDACControlRegister, currentValue))
    {
        uint8_t newValue = (currentValue & ~updateMask) | (controlValue & updateMask);
        writeDACRegister(kDACControlRegister, newValue);
    }
}

void setVolume(uint8_t volume)
{
    writeDACRegister(kDACVolumetRegister, volume);
}

void setDither(bool enable)
{
    updateDACControl(enable ? (1 << kDACControlDither) : 0, 1 << kDACControlDither);
}

void setTestTone(bool enable)
{
    updateDACControl(enable ? (1 << kDACControlTestTone) : 0, 1 << kDACControlTestTone);
}

void setInhibitInterpolation(bool enable)
{
    updateDACControl(enable ? (1 << kDACControlInhibitInterpolation) : 0, 1 << kDACControlInhibitInterpolation);
}

void setInputMute(bool enable)
{
    updateDACControl(enable ? (1 << kDACControlInputMute) : 0, 1 << kDACControlInputMute);
}

void setOutputMute(bool enable)
{
    updateDACControl(enable ? (1 << kDACControlOutputMute) : 0, 1 << kDACControlOutputMute);
}

void setup()
{
    Serial.begin(9600);
    Wire.begin();
    lcd.init();
    lcd.backlight();
    lcd.setCursor(0, 0);

    // Make pin 3 an input with an internal pull-up resistor
    pinMode(4, INPUT_PULLUP);
    pinMode(1, INPUT_PULLUP); 
    pinMode(3, INPUT_PULLUP); // For the rotary encoder

    ditherButton.attachClick([]() {
        ditherEnabled = !ditherEnabled;
        setDither(ditherEnabled);
        forceDisplayUpdate = true;
    });

    volumeKnob.setMaxPosition(255);
    volumeKnob.setMinPosition(0);
    volumeKnob.setPosition(128);

    setDither(ditherEnabled);
    setVolume(128);
}

void loop()
{
    static DACStatus status = {0.0, 0, false, false, false, false, false};
    static time_t lastUpdate = 0;
    long volume;

    // Tick the controls
    ditherButton.tick();
    volumeKnob.tick();

    if (volumeKnob.getNewPosition(volume)) {
        setVolume(volume);
        forceDisplayUpdate = true;
    }

    // Time to update?
    if (forceDisplayUpdate || (millis() - lastUpdate >= 1000))
    {
        readDACStatus(status);
        printDACStatus(status);

        uint8_t low, high;
        readDACRegister(10, low);
        readDACRegister(11, high);
        uint16_t servoFifo =
            uint16_t(low) |
            (uint16_t(high) << 8);

        forceDisplayUpdate = false;
        lastUpdate = millis();
        Serial.printf("ASRC Error: %d, ASRC Adjustment: %d, FIFO: %u, Servo FIFO: %u\n", status.asrcError, status.asrcAdjustment, status.fifoFullness, servoFifo);
        Serial.printf("FIFO servo bytes: %02X %02X\n", low, high);

        uint8_t lo, hi;
        readDACRegister(0x0C, lo);
        readDACRegister(0x0D, hi);
        uint16_t debugCounter = uint16_t(lo) | (uint16_t(hi) << 8);
        Serial.printf("Debug Counter: %04x\n", debugCounter);
    }
}

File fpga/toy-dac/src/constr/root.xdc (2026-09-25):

## This file is a general .xdc for the Cmod S7-25 Rev. B
## To use it in a project:
## - uncomment the lines corresponding to used pins
## - rename the used ports (in each line, after get_ports) according to the top level signal names in the project

## 12 MHz System Clock
set_property -dict {PACKAGE_PIN M9 IOSTANDARD LVCMOS33} [get_ports clk]
create_clock -period 83.330 -name sys_clk_pin -waveform {0.000 41.660} [get_ports clk]

## External clocks
create_clock -period 44.288 -name ext_clk1_pin -waveform {0.000 22.144} [get_ports ext_clk1]
create_clock -period 40.690 -name ext_clk2_pin -waveform {0.000 20.345} [get_ports ext_clk2]

# ext_clk1/ext_clk2 both reach the BUFGMUX in external_clock (clock.v)
# but only one drives sclk at a time — the other input is a genuinely
# independent, unrelated oscillator, not just an unused path. Without
# this, Vivado has no way to know the two clocks never coexist and
# tries to close timing between them (and between either one and
# mclk) through every sclk-domain register, which is both impossible
# (unrelated clocks) and very slow to route around. sclk_bridge.v is
# the only crossing point between mclk and sclk, and it's built from
# 2-FF synchronizers / an async-assert reset bridge, not timed paths.
set_clock_groups -asynchronous \
    -group [get_clocks sys_clk_pin] \
    -group [get_clocks ext_clk1_pin] \
    -group [get_clocks ext_clk2_pin]

## Push Buttons
set_property -dict {PACKAGE_PIN D2 IOSTANDARD LVCMOS33} [get_ports {btn[0]}]
set_property -dict {PACKAGE_PIN D1 IOSTANDARD LVCMOS33} [get_ports {btn[1]}]

## RGB LEDs
set_property -dict {PACKAGE_PIN F1 IOSTANDARD LVCMOS33} [get_ports led0_b]
#set_property -dict { PACKAGE_PIN D3    IOSTANDARD LVCMOS33 } [get_ports { led0_g }]; #IO_L9N_T1_DQS_34 Sch=led0_g
#set_property -dict { PACKAGE_PIN F2    IOSTANDARD LVCMOS33 } [get_ports { led0_r }]; #IO_L10P_T1_34 Sch=led0_r

## 4 LEDs
set_property -dict {PACKAGE_PIN E2 IOSTANDARD LVCMOS33} [get_ports {led[0]}]
set_property -dict {PACKAGE_PIN K1 IOSTANDARD LVCMOS33} [get_ports {led[1]}]
set_property -dict {PACKAGE_PIN J1 IOSTANDARD LVCMOS33} [get_ports {led[2]}]
set_property -dict {PACKAGE_PIN E1 IOSTANDARD LVCMOS33} [get_ports {led[3]}]

## Pmod Header JA
set_property -dict { PACKAGE_PIN J2    IOSTANDARD LVCMOS33 } [get_ports { ext_clk1_enable }]; #IO_L14P_T2_SRCC_34 Sch=ja[1]
set_property -dict { PACKAGE_PIN H2    IOSTANDARD LVCMOS33 } [get_ports { ext_clk2_enable }]; #IO_L14N_T2_SRCC_34 Sch=ja[2]
set_property -dict { PACKAGE_PIN H4    IOSTANDARD LVCMOS33 } [get_ports { ext_clk1 }]; #IO_L13P_T2_MRCC_34 Sch=ja[3]
# ext_clk2 must be on the P-side of its clock-capable pair to drive a
# BUFGMUX (PLIO-9); F3 is the N-side of the same L11 pair, moved to
# ja[10] (F4) instead — requires re-wiring the oscillator to ja[10].
#set_property -dict { PACKAGE_PIN F4    IOSTANDARD LVCMOS33 } [get_ports { ext_clk2 }]; #IO_L11P_T1_SRCC_34 Sch=ja[10]
#set_property -dict { PACKAGE_PIN H3    IOSTANDARD LVCMOS33 } [get_ports { ja[4] }]; #IO_L13N_T2_MRCC_34 Sch=ja[7]
set_property -dict { PACKAGE_PIN G1    IOSTANDARD LVCMOS33 } [get_ports { ext_clk2 }]; #IO_L12P_T1_MRCC_34 Sch=ja[8]
#set_property -dict { PACKAGE_PIN G1    IOSTANDARD LVCMOS33 } [get_ports { ja[6] }]; #IO_L12N_T1_MRCC_34 Sch=ja[9]
#set_property -dict { PACKAGE_PIN F3    IOSTANDARD LVCMOS33 } [get_ports { ja[7] }]; #IO_L11N_T1_SRCC_34 Sch=ja[4]

## USB UART
## Note: Port names are from the perspoctive of the FPGA.
#set_property -dict { PACKAGE_PIN L12   IOSTANDARD LVCMOS33 } [get_ports { uart_tx }]; #IO_L6N_T0_D08_VREF_14 Sch=uart_rxd_out
#set_property -dict { PACKAGE_PIN K15   IOSTANDARD LVCMOS33 } [get_ports { uart_rx }]; #IO_L5N_T0_D07_14 Sch=uart_txd_in

## Analog Inputs on PIO Pins 32 and 33
#set_property -dict {PACKAGE_PIN A13 IOSTANDARD LVCMOS33} [get_ports vaux5_p]
#set_property -dict {PACKAGE_PIN A14 IOSTANDARD LVCMOS33} [get_ports vaux5_n]
#set_property -dict { PACKAGE_PIN A11   IOSTANDARD LVCMOS33 } [get_ports { vaux12_p }]; #IO_L11P_T1_SRCC_AD12P_15 Sch=ain_p[33]
#set_property -dict { PACKAGE_PIN A12   IOSTANDARD LVCMOS33 } [get_ports { vaux12_n }]; #IO_L11N_T1_SRCC_AD12N_15 Sch=ain_n[33]

## Dedicated Digital I/O on the PIO Headers

# I2S Audio Interface
set_property -dict {PACKAGE_PIN L1 IOSTANDARD LVCMOS33} [get_ports lrclk]
set_property -dict {PACKAGE_PIN M4 IOSTANDARD LVCMOS33} [get_ports bclk]
set_property -dict {PACKAGE_PIN M3 IOSTANDARD LVCMOS33} [get_ports din]
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

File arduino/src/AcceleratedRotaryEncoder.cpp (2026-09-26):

#include "AcceleratedRotaryEncoder.h"

AcceleratedRotaryEncoder::AcceleratedRotaryEncoder(
    int pin1,
    int pin2,
    LatchMode mode,
    unsigned long slowCutoffMs,
    unsigned long fastCutoffMs,
    long maximumMultiplier)
    : RotaryEncoder(pin1, pin2, mode),
      slowCutoffMs_(slowCutoffMs),
      fastCutoffMs_(fastCutoffMs),
      maximumMultiplier_(maximumMultiplier),
      rawPosition_(RotaryEncoder::getPosition()),
      acceleratedPosition_(rawPosition_),
      lastDirection_(0)
{
}

void AcceleratedRotaryEncoder::tick()
{
    RotaryEncoder::tick();
    updateAcceleratedPosition();
}

void AcceleratedRotaryEncoder::tick(int sig1, int sig2)
{
    RotaryEncoder::tick(sig1, sig2);
    updateAcceleratedPosition();
}

long AcceleratedRotaryEncoder::getPosition()
{
    return acceleratedPosition_;
}

void AcceleratedRotaryEncoder::setPosition(long newPosition)
{
    RotaryEncoder::setPosition(newPosition);
    rawPosition_ = RotaryEncoder::getPosition();
    acceleratedPosition_ = newPosition;
    lastDirection_ = 0;
    hasNewPosition_ = true;
}

bool AcceleratedRotaryEncoder::getNewPosition(long& newPosition)
{
    if (hasNewPosition_) {
        newPosition = acceleratedPosition_;
        hasNewPosition_ = false;
        return true;
    }
    return false;
}

void AcceleratedRotaryEncoder::updateAcceleratedPosition()
{
    long newRawPosition = RotaryEncoder::getPosition();
    long rawDelta = newRawPosition - rawPosition_;
    if (rawDelta == 0) {
        return;
    }

    unsigned long intervalMs = getMillisBetweenRotations();
    long multiplier = 1;
    long lastAcceleratedPosition = acceleratedPosition_;
    int8_t direction = rawDelta > 0 ? 1 : -1;
    if (lastDirection_ == direction && intervalMs < slowCutoffMs_) {
        if (intervalMs < fastCutoffMs_) {
            intervalMs = fastCutoffMs_;
        }
        multiplier = 1 + ((slowCutoffMs_ - intervalMs) *
                          (maximumMultiplier_ - 1)) /
                         (slowCutoffMs_ - fastCutoffMs_);
        if (multiplier > maximumMultiplier_) {
            multiplier = maximumMultiplier_;
        }
    }

    acceleratedPosition_ += rawDelta * multiplier;
    if (hasMax_ && acceleratedPosition_ > maxPosition_) {
        acceleratedPosition_ = maxPosition_;
    }
    if (hasMin_ && acceleratedPosition_ < minPosition_) {
        acceleratedPosition_ = minPosition_;
    }
    if (acceleratedPosition_ != lastAcceleratedPosition) {
        hasNewPosition_ = true;
    }
    rawPosition_ = newRawPosition;
    lastDirection_ = direction;
}

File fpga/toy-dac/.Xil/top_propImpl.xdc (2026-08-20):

set_property SRC_FILE_INFO {cfile:C:/proj/toy-dac/fpga/toy-dac/src/constr/root.xdc rfile:../src/constr/root.xdc id:1} [current_design]
set_property src_info {type:XDC file:1 line:7 export:INPUT save:INPUT read:READ} [current_design]
set_property -dict {PACKAGE_PIN M9 IOSTANDARD LVCMOS33} [get_ports clk]
set_property src_info {type:XDC file:1 line:11 export:INPUT save:INPUT read:READ} [current_design]
set_property -dict {PACKAGE_PIN D2 IOSTANDARD LVCMOS33} [get_ports {btn[0]}]
set_property src_info {type:XDC file:1 line:12 export:INPUT save:INPUT read:READ} [current_design]
set_property -dict {PACKAGE_PIN D1 IOSTANDARD LVCMOS33} [get_ports {btn[1]}]
set_property src_info {type:XDC file:1 line:15 export:INPUT save:INPUT read:READ} [current_design]
set_property -dict {PACKAGE_PIN F1 IOSTANDARD LVCMOS33} [get_ports led0_b]
set_property src_info {type:XDC file:1 line:20 export:INPUT save:INPUT read:READ} [current_design]
set_property -dict {PACKAGE_PIN E2 IOSTANDARD LVCMOS33} [get_ports {led[0]}]
set_property src_info {type:XDC file:1 line:21 export:INPUT save:INPUT read:READ} [current_design]
set_property -dict {PACKAGE_PIN K1 IOSTANDARD LVCMOS33} [get_ports {led[1]}]
set_property src_info {type:XDC file:1 line:22 export:INPUT save:INPUT read:READ} [current_design]
set_property -dict {PACKAGE_PIN J1 IOSTANDARD LVCMOS33} [get_ports {led[2]}]
set_property src_info {type:XDC file:1 line:23 export:INPUT save:INPUT read:READ} [current_design]
set_property -dict {PACKAGE_PIN E1 IOSTANDARD LVCMOS33} [get_ports {led[3]}]
set_property src_info {type:XDC file:1 line:26 export:INPUT save:INPUT read:READ} [current_design]
set_property -dict { PACKAGE_PIN J2    IOSTANDARD LVCMOS33 SLEW FAST} [get_ports { dac_out_l_fast }]; #IO_L14P_T2_SRCC_34 Sch=ja[1]
set_property src_info {type:XDC file:1 line:27 export:INPUT save:INPUT read:READ} [current_design]
set_property -dict { PACKAGE_PIN H2    IOSTANDARD LVCMOS33 SLEW FAST} [get_ports { dac_out_ln_fast }]; #IO_L14N_T2_SRCC_34 Sch=ja[2]
set_property src_info {type:XDC file:1 line:49 export:INPUT save:INPUT read:READ} [current_design]
set_property -dict {PACKAGE_PIN L1 IOSTANDARD LVCMOS33} [get_ports lrclk]
set_property src_info {type:XDC file:1 line:50 export:INPUT save:INPUT read:READ} [current_design]
set_property -dict {PACKAGE_PIN M4 IOSTANDARD LVCMOS33} [get_ports bclk]
set_property src_info {type:XDC file:1 line:51 export:INPUT save:INPUT read:READ} [current_design]
set_property -dict {PACKAGE_PIN M3 IOSTANDARD LVCMOS33} [get_ports din]
set_property src_info {type:XDC file:1 line:58 export:INPUT save:INPUT read:READ} [current_design]
set_property -dict {PACKAGE_PIN P3 IOSTANDARD LVCMOS33 PULLDOWN TRUE} [get_ports bypass]
set_property src_info {type:XDC file:1 line:62 export:INPUT save:INPUT read:READ} [current_design]
set_property -dict {PACKAGE_PIN B4 IOSTANDARD LVCMOS33} [get_ports {fifo_led[0]}]
set_property src_info {type:XDC file:1 line:63 export:INPUT save:INPUT read:READ} [current_design]
set_property -dict {PACKAGE_PIN B3 IOSTANDARD LVCMOS33} [get_ports {fifo_led[1]}]
set_property src_info {type:XDC file:1 line:64 export:INPUT save:INPUT read:READ} [current_design]
set_property -dict {PACKAGE_PIN C1 IOSTANDARD LVCMOS33} [get_ports {fifo_led[2]}]
set_property src_info {type:XDC file:1 line:65 export:INPUT save:INPUT read:READ} [current_design]
set_property -dict {PACKAGE_PIN B1 IOSTANDARD LVCMOS33} [get_ports {fifo_led[3]}]
set_property src_info {type:XDC file:1 line:66 export:INPUT save:INPUT read:READ} [current_design]
set_property -dict {PACKAGE_PIN B2 IOSTANDARD LVCMOS33} [get_ports {fifo_led[4]}]
set_property src_info {type:XDC file:1 line:86 export:INPUT save:INPUT read:READ} [current_design]
set_property -dict {PACKAGE_PIN A2 IOSTANDARD LVCMOS33} [get_ports debug1]
set_property src_info {type:XDC file:1 line:87 export:INPUT save:INPUT read:READ} [current_design]
set_property -dict {PACKAGE_PIN C5 IOSTANDARD LVCMOS33} [get_ports debug2]
set_property src_info {type:XDC file:1 line:88 export:INPUT save:INPUT read:READ} [current_design]
set_property -dict {PACKAGE_PIN N3 IOSTANDARD LVCMOS33} [get_ports debug3]
set_property src_info {type:XDC file:1 line:89 export:INPUT save:INPUT read:READ} [current_design]
set_property -dict {PACKAGE_PIN P1 IOSTANDARD LVCMOS33} [get_ports debug4]
set_property src_info {type:XDC file:1 line:94 export:INPUT save:INPUT read:READ} [current_design]
set_property -dict {PACKAGE_PIN A4 IOSTANDARD LVCMOS33 SLEW FAST DRIVE 12} [get_ports dac_out_l]
set_property src_info {type:XDC file:1 line:95 export:INPUT save:INPUT read:READ} [current_design]
set_property -dict {PACKAGE_PIN A3 IOSTANDARD LVCMOS33 SLEW FAST DRIVE 12} [get_ports dac_out_ln]
set_property src_info {type:XDC file:1 line:96 export:INPUT save:INPUT read:READ} [current_design]
set_property -dict {PACKAGE_PIN K14 IOSTANDARD LVCMOS33 SLEW FAST DRIVE 12} [get_ports dac_out_r]
set_property src_info {type:XDC file:1 line:97 export:INPUT save:INPUT read:READ} [current_design]
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

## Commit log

2026-04-24 Added PCB
    [dac-B_Cu.gbr, dac-B_Mask.gbr, dac-B_Paste.gbr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]
2026-04-27 feat: add multirate (44.1/48 kHz) and bypass support to ASRC
    - nco.v: add inc_nominal_in port for runtime NCO frequency override
    - asrc.v: add inc_nominal_in port, pass through to internal NCO
    - root.v:
    * add bypass input port (already pinned in XDC)
    * wire lrclk_pos_edge from i2s instance
    * instantiate rate_detect to measure LRCLK period
    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
2026-04-29 Removed junk files
    [asrc_tb_audio.csv, asrc_tb_audio_44k1.csv, asrc_tb_audio_48k.csv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]
2026-05-02 Increased internal sample rate
2026-05-07 Fixed adjust LED blink
    [root.xdc]
2026-07-18 First run of v2.0
    [dac-ng.kicad_pcb, dac-ng.kicad_sch, dac.kicad_pcb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]
2026-07-21 Distortion reduction
    [dac-ng.kicad_sch, output.kicad_sch]
2026-08-27 Before external clock
    [clock-B_Cu.gbr, clock-B_Mask.gbr, clock-B_Paste.gbr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]
2026-09-25 I2C debugged
2026-09-26 Added Arduino code
